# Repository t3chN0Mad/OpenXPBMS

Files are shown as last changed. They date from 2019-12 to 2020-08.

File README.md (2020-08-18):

# OpenXPBMS
An Open Source BMS(Battery Management System) for Valence XP Batteries that communicates with the built-in modules over the factory communication cables. The goal of this project is not to reproduce all of the functionality available through the vendor diagnostic app. The BMS only has to read a very small subset of the total data available from the built in modules to determine if it should continue to allow the battery or batteries to maintain connected to the system. The BMS does NOT make any write changes to the module; it is only listening.
# Status : Early Development
## This repo has three main sections
### BMS 
Arduino sketch to run the actual BMS. At this point, it is in early stages on development. Full functionality for monitoring (1) battery has been implemented! CRC HAS NOW BEEN IMPLEMENTED! Please post feedback on use with multiple batteries!
Hop over to [https://diysolarforum.com/threads/interfacing-with-valence-built-in-monitoring.2183/] for more information.
### PCB
This directory now has a basic KiCad schematic showing how the modules should be connected together. In the future there will also be KiCad PCB design files in order to solder everything to one board.
### Utilities
Scripts and other tools to run from a PC for diagnostic or research purposes.
There is one script here currently. It allows you to obtain voltage and temperature readings from a battery assigned to ID 1 using python.
## The general gist of how to communicate with the built-in modules
Each battery communicates using a protocol similar to MODBUS over RS485.
First a wake up command is broadcast over RS485 to wake up any battery modules on the line.
Immediately after the broadcast command is sent, a request has to be made. In this projects's case, we make requests to a specific battery to read holding registers that contain the voltage and temperature information for that battery.
The built in modules listen to the request and the module that is being requested responds with it's information.

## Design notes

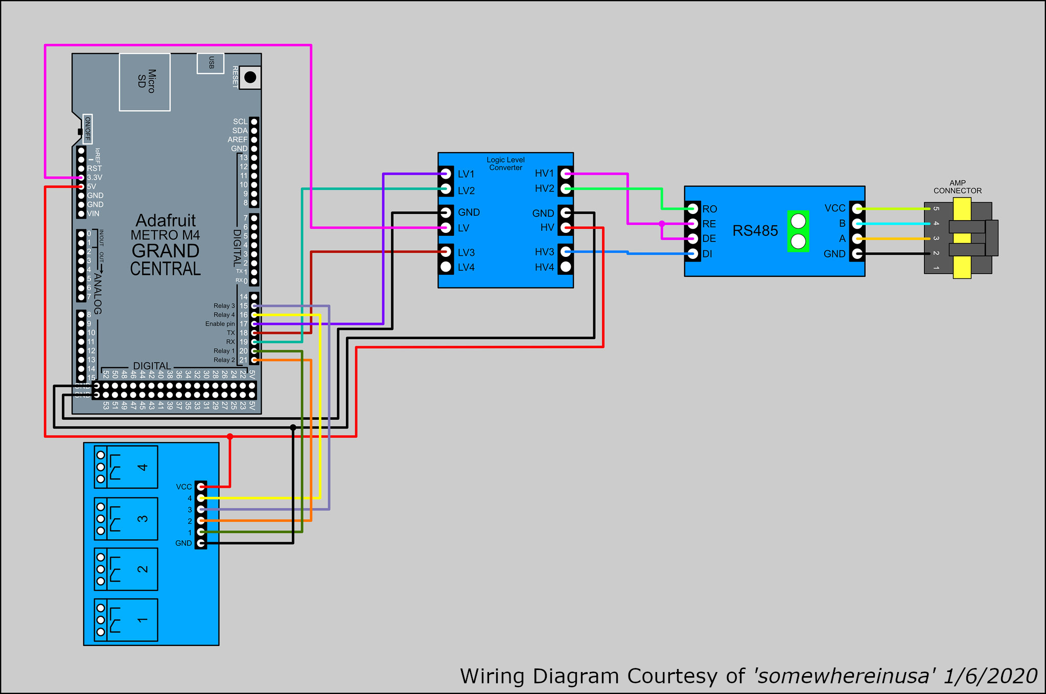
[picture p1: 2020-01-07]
PCB/diagram.jpg

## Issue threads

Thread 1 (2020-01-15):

Logic for temps below 0

t3chN0Mad, 2020-01-15:
Temperatures below 0 degrees C are displayed as positive instead of negative. Additional logic needed to ensure values are being converted correctly.

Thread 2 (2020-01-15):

Relays remain ON after failure to read battery data

t3chN0Mad, 2020-01-15:
Relays are remaining on after a failure to read data from the battery. In order to ensure safe operation, we want to make sure the relays disconnect after a certain number of failures to read data. Currently, there is logic to allow for a specified number of failures to happen before disconnecting the relays, but that logic is not working. Test with 1 failure triggering logic and keep it user adjustable.

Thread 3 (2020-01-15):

PCB needs revision

t3chN0Mad, 2020-01-15:
Everything works, but I did discover a couple of problems which were totally my fault: I routed the traces for the RS485 module backwards. Also, the two headers of pins for the the grand central are out of alignment with each other by roughly .5-1mm. Lastly, there are two sets of holes for pins at the bottom of the RS485 module. This was to provide soldering points for the wires going to the AMP connector in line with the pins on the RS485 module. I connected the outer four respectively, but did not put traces on the inner four.

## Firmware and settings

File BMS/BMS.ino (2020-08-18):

//
//  ____                _  _____  ___  __  _______
// / __ \___  ___ ___  | |/_/ _ \/ _ )/  |/  / __/
/// /_/ / _ \/ -_) _ \_>  </ ___/ _  / /|_/ /\ \  
//\____/ .__/\__/_//_/_/|_/_/  /____/_/  /_/___/
//    /_/
//
//
// This sketch requires an Adafruit Metro M4 Express and a relay module board with a minimum of 2 relays.
// It also requires an RS485 transceiver and logic level converter.
// It was tested using an Adafruit Grand Central M4 Express.
// It is recommended to use the relays connected to the controller to drive higher capacity automotive/industrial relays sized appropriately for your system.
// This sketch is released under GPLv3 and comes with no warrany or guarantees. Use at your own risk!
// Libraries used in this sketch may have licenses that differ from the one governing this sketch.
// Please consult the repositories of those libraries for information.

#include <Arduino.h> // required before wiring_private.h
#include <Adafruit_NeoPixel.h>
#include <SD.h>
#include "wiring_private.h" // pinPeripheral() function

// Set digital out pin numbers for relays. r1 is the battery disconnect and r2 is a pv array disconnect.
// In theory, you could add as many relays as you have digital outputs to isolate each battery in your bank if you wish.
// Modifications to the sketch are neccessary to accommodate extra relays/isolation.
#define r1 20
#define r2 21

#define enablePin 17

// Set slave numbers for batteries you want to communicate
byte batteries[] = {0x01};
// Set BMS thresholds - mV and C
unsigned int battHighV = 3600;
unsigned int battLowV = 3000;
unsigned int battHighT = 6000;
unsigned int battLowT = 0200;
// The loop will change one or both of these depending on the data from the batteries.
bool r1status = true;
bool r2status = true;
// Commands to send to the batteries.
byte messageW[] = {0x00, 0x00, 0x01, 0x01, 0xc0, 0x74, 0x0d, 0x0a, 0x00, 0x00};
byte readVolts[] = {0x00, 0x03, 0x00, 0x45, 0x00, 0x09, 0x00, 0x00, 0x0d, 0x0a};
byte readTemps[] = {0x00, 0x03, 0x00, 0x50, 0x00, 0x07, 0x00, 0x00, 0x0d, 0x0a};

// Pin number and count for onboard NeoPixel. It is used as a status indicator.
unsigned int npp = 88;
unsigned int npc = 1;
Adafruit_NeoPixel np(npc, npp);

// SERCOM UART Serial used to communicate with the battery
Uart Serial2(&sercom4, PIN_SERIAL2_RX, PIN_SERIAL2_TX, PAD_SERIAL2_RX, PAD_SERIAL2_TX);

unsigned long startTime;
unsigned long currentTime;
unsigned long interval = 750;

void setup()
{

  // NeoPixel starts out red
  np.begin();
  np.show();
  np.setPixelColor(0, 255, 0, 0);
  np.show();

  // Start console serial
  Serial.begin(115200);

  pinMode(enablePin, OUTPUT);

  // Start SD card interface for datalogging
  if (!SD.begin(SDCARD_SS_PIN))
  {
    Serial.println("SD card failed to initialize. No data will be logged. :(");
  }

  // Make sure relays are "OFF" until BMS has received data from battery and determined it is safe to enable
  pinMode(r1, INPUT_PULLUP);
  pinMode(r2, INPUT_PULLUP);

  // Broadcast wakeup message to batteries
  wakeup();

  Serial2.begin(115200, SERIAL_8E1);
}

void loop()
{
  // We want to keep track of serial read errors and how many batteries are in a good state.
  unsigned int countFailures = 0;

  // Iterate through all of the batteries connected to the BMS.
  for (int i = 0; i < sizeof(batteries) / sizeof(byte); i++)
  {
    readVolts[0] = batteries[i];
    readVolts[6] = lowByte(ModRTU_CRC(readVolts, 6));
    readVolts[7] = highByte(ModRTU_CRC(readVolts, 6));
    preTransmission();
    startTime = millis();
    Serial2.write(readVolts, sizeof(readVolts));
    Serial2.flush();
    postTransmission();
    byte resV[25];
    currentTime = millis();
    while (currentTime - startTime < interval)
    {
      currentTime = millis();
    }
    while (Serial2.available() > 0)
    {
      if (Serial2.available() >= 25)
      {
        unsigned int bytesToRead = Serial2.available();
        for (int a = 0; a < bytesToRead; a++)
        {
          byte b = Serial2.read();
          resV[a] = b;
        }
        unsigned int volts[4] = {(resV[9] * 256) + resV[10], (resV[11] * 256) + resV[12], (resV[13] * 256) + resV[14], (resV[15] * 256) + resV[16]};
        logData("V1: " + String(volts[0]));
        logData(" V2: " + String(volts[1]));
        logData(" V3: " + String(volts[2]));
        logData(" V4: " + String(volts[3]));
        logData(" Total: " + String(volts[0] + volts[1] + volts[2] + volts[3]));
        // Clean out the buffer after reading the response
        while (Serial.available())
          Serial.read();
        // Check and make sure no cells are out of thresholds
        for (int a = 0; a < sizeof(volts) / sizeof(volts[0]); a++)
        {
          if (volts[a] > battHighV)
          {
            // Change this to suit your high voltage threshold strategy. You can disconnect both, or just the pv array. Since there is a possibility of power being backfed through a circuit that is normally drawing power, I am defaulting to shutting everything down.
            shutdownAll();
            //shutdownPv();
            break;
          }
          else if (volts[a] < battLowV)
          {
            // Ideally, we could use a 3rd relay to shut off load and allow the battery to charge in this condition, but for now we have to disconnect everything.
            shutdownAll();
            break;
          }
          else
          {
            // All is good. We'll do stuff here eventually when implementing auto reconnect.
          }
        }
      }
      else
      {
        // Couldn't read voltage, so we want to increment the failure counter and if it is more than 1, we want disable the relays and start over. Otherwise we'll let it go.
        countFailures++;
        if (countFailures > 1)
        {
          shutdownAll();
          break;
        }
      }
    }
    readTemps[0] = batteries[i];
    readTemps[6] = lowByte(ModRTU_CRC(readTemps, 6));
    readTemps[7] = highByte(ModRTU_CRC(readTemps, 6));
    preTransmission();
    startTime = millis();
    Serial2.write(readTemps, sizeof(readTemps));
    Serial2.flush();
    postTransmission();
    byte resT[21];
    currentTime = millis();
    while (currentTime - startTime < interval)
    {
      currentTime = millis();
    }
    while (Serial2.available() > 0)
    {
      if (Serial2.available() >= 21)
      {
        unsigned int bytesToRead = Serial2.available();
        for (int a = 0; a < bytesToRead; a++)
        {
          byte b = Serial2.read();
          resT[a] = b;
        }
        int temps[5] = {(resT[5] * 256) + resT[6], (resT[7] * 256) + resT[8], (resT[9] * 256) + resT[10], (resT[11] * 256) + resT[12], (resT[3] * 256) + resT[4]};
        logData(" T1: " + String(temps[0]));
        logData(" T2: " + String(temps[1]));
        logData(" T3: " + String(temps[2]));
        logData(" T4: " + String(temps[3]));
        logData(" T5: " + String(temps[4]));
        //clean out the buffer after reading the response
        while (Serial.available())
          Serial.read();
        for (int a = 0; a < sizeof(temps) / sizeof(temps[0]); a++)
        {
          if (temps[a] > battHighT)
          {
            shutdownAll();
            break;
          }
          else if (temps[a] < battLowT)
          {
            // We can allow the batteries to dischage, but we don't want to charge them
            shutdownPv();
            break;
          }
          else
          {
            // All is good. We'll do stuff here eventually when implementing auto reconnect.
          }
        }
      }
      else
      {
        // Couldn't read temperature, so we want to increment the failure counter and if it is more than 1, we want disable the relays and start over. Otherwise we'll let it go.
        countFailures++;
        if (countFailures > 1)
        {
          shutdownAll();
          break;
        }
      }
    }
  }

  //Light up the NeoPixel with the correct status color according to relay status(Green-Both ON, Orange-Solar OFF/Main ON, Red-Both OFF) Solar ON/Main OFF should not be possible!


  // Read status' and see if the relays should be enabled
  if (r1status) {
    idw(r1, true);
  }
  if (r2status) {
    idw(r2, true);
  }

  setNP();

  logData(" r1: " + String(idr(r1)));
  logData(" r2: " + String(idr(r2)));

  //clean out the buffer again, just in case there were more or less bytes
  while (Serial.available())
    Serial.read();

  currentTime = millis();
  while (currentTime - startTime < interval)
  {
    //If everything runs at the fastest speed possible, we want to make sure there is enough time between Serial2 messages when restarting the loop.
    currentTime = millis();
  }
  // End current line in log before looping
  logData("\r\n");
}

// Gives actual status of the relays, which is inverse of the pin(idr-invert digitalRead)
bool idr(unsigned int r) {
  if (digitalRead(r))
  {
    return false;
  }
  return true;
}

// Same purpose as above, just for write(idw-invert digitalWrite)
void idw(unsigned int r, bool state) {
  pinMode(r, OUTPUT);
  if (state)
  {
    digitalWrite(r, LOW);
    return;
  }
  digitalWrite(r, HIGH);
  return;
}

// Data logging and console output all in one!
void logData(String data) {
  File dataLog = SD.open("datalog.txt", FILE_WRITE);
  if (dataLog) {
    dataLog.print(data);
    dataLog.close();
  } else {
    Serial.println("Can't open SD datalog file.");
  }
  Serial.print(data);
}

//Needed for RS485 half duplex communication
void preTransmission() {
  digitalWrite(enablePin, 1);
  //delay(1);
}

void postTransmission() {
  digitalWrite(enablePin, 0);
  //delay(1);
}

void wakeup() {
  Serial2.begin(9600, SERIAL_8N2);
  preTransmission();
  Serial2.write(messageW, sizeof(messageW));
  Serial2.flush();
  postTransmission();
}

void shutdownAll() {
  // Shutdown pv array first
  r2status = false;
  idw(r2, r2status);
  // Wait a half second for pv array to disconnect, then disconnect battery
  delay(500);
  r1status = false;
  idw(r1, r1status);
  setNP();
  logData("Entire system was disconnected.");
}

void shutdownPv() {
  // Shutdown pv array, leave battery alone.
  r2status = false;
  idw(r2, r2status);
  setNP();
  logData("Pv array was disconnected.");
}

void setNP() {
  if (r1status && r2status) {
    np.setPixelColor(0, 0, 10, 0);
    np.show();
  }
  else if (r1status && !r2status) {
    np.setPixelColor(0, 10, 2, 0);
    np.show();
  } else {
    np.setPixelColor(0, 10, 0, 0);
    np.show();
  }
}

// ISR Handlers for Serial2
void SERCOM4_0_Handler()
{
  Serial2.IrqHandler();
}
void SERCOM4_1_Handler()
{
  Serial2.IrqHandler();
}
void SERCOM4_2_Handler()
{
  Serial2.IrqHandler();
}
void SERCOM4_3_Handler()
{
  Serial2.IrqHandler();
}

// Compute the MODBUS RTU CRC
// Adapted from https://ctlsys.com/support/how_to_compute_the_modbus_rtu_message_crc/
uint16_t ModRTU_CRC(byte buf[], int len)
{
  uint16_t crc = 0xFFFF;
  
  for (int pos = 0; pos < len; pos++) {
    crc ^= (uint16_t)buf[pos];          // XOR byte into least sig. byte of crc
  
    for (int i = 8; i != 0; i--) {    // Loop over each bit
      if ((crc & 0x0001) != 0) {      // If the LSB is set
        crc >>= 1;                    // Shift right and XOR 0xA001
        crc ^= 0xA001;
      }
      else                            // Else LSB is not set
        crc >>= 1;                    // Just shift right
    }
  }
  // Note, this number has low and high bytes swapped, so use it accordingly (or swap bytes)
  return crc;  
};

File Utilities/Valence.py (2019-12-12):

#
#  ____                _  _____  ___  __  _______
# / __ \___  ___ ___  | |/_/ _ \/ _ )/  |/  / __/
#/ /_/ / _ \/ -_) _ \_>  </ ___/ _  / /|_/ /\ \  
#\____/ .__/\__/_//_/_/|_/_/  /____/_/  /_/___/  
#    /_/                                         
#
#
# This script requires a USB to RS485 adapter terminated with a Tyco AMP connector.
# It was tested on Windows using an FTDI cable. It will print battery voltage and temperature data for battery 1 to the console.
# This code is released under GPLv3 and comes with no warrany or guarantees. Use at your own risk!

import serial
import libscrc

sPort = 'COM1'
payloadW = [0x00,0x00,0x01,0x01,0xc0,0x74,0x0d,0x0a,0x00,0x00]
payloadV = [0x01,0x03,0x00,0x45,0x00,0x09,0x94,0x19,0x0d,0x0a]
payloadT = [0x01,0x03,0x00,0x50,0x00,0x07,0x04,0x19,0x0d,0x0a]

s = serial.Serial(
    port = sPort,
    baudrate=9600,
    parity=serial.PARITY_MARK,
    stopbits=serial.STOPBITS_ONE,
    bytesize=serial.EIGHTBITS,
    timeout=1
)
s.write(serial.to_bytes(payloadW))
#print("Woke up serial device")
s.flush()
s.close()

s = serial.Serial(
    port = sPort,
    baudrate=115200,
    parity=serial.PARITY_MARK,
    stopbits=serial.STOPBITS_ONE,
    bytesize=serial.EIGHTBITS,
    timeout=1
)
s.write(serial.to_bytes(payloadV))
outputV = s.readline()
s.write(serial.to_bytes(payloadT))
outputT = s.readline()
s.close()

volts=[(outputV[9] * 256) + outputV[10],
    (outputV[11] * 256) + outputV[12],
    (outputV[13] * 256) + outputV[14],
    (outputV[15] * 256) + outputV[16]
]
volts.append(volts[0]+volts[1]+volts[2]+volts[3])

temps=[(outputT[5] * 256) + outputT[6],
    (outputT[7] * 256) + outputT[8],
    (outputT[9] * 256) + outputT[10],
    (outputT[11] * 256) + outputT[12],
    (outputT[3] * 256) + outputT[4]
]
for value in volts: 
    print(value)
for value in temps: 
    print(value)

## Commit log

2020-01-02 reads voltage from one battery
2020-01-04 full functionality for one battery
2020-01-04 fixed pinMode and neopixel bugs
    [BMS.ino]
2020-01-05 Added KiCad schematic
    [PCB.kicad_pcb, PCB.sch]
2020-01-07 Added PCB design files and wiring diagram
    [PCB-B_Cu.gbr, PCB-B_Mask.gbr, PCB-B_Paste.gbr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]
2020-08-18 Implemented CRC / Multiple battery support
